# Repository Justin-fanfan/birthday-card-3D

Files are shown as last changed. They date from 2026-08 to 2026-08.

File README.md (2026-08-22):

# birthday-card-3D

用于生日礼物的 **掼蛋牌架 + A/B 双滑槽计级器 + 可插拔红桃 A 二维码展示牌**。

这一版把原来的独立横梁和旋钮结构改成了更接近 AI 参考模型的一体式外形：三层牌槽下方完全填充并彼此连接，装配预览中只保留中间的红桃 A，不再摆放其它演示牌。

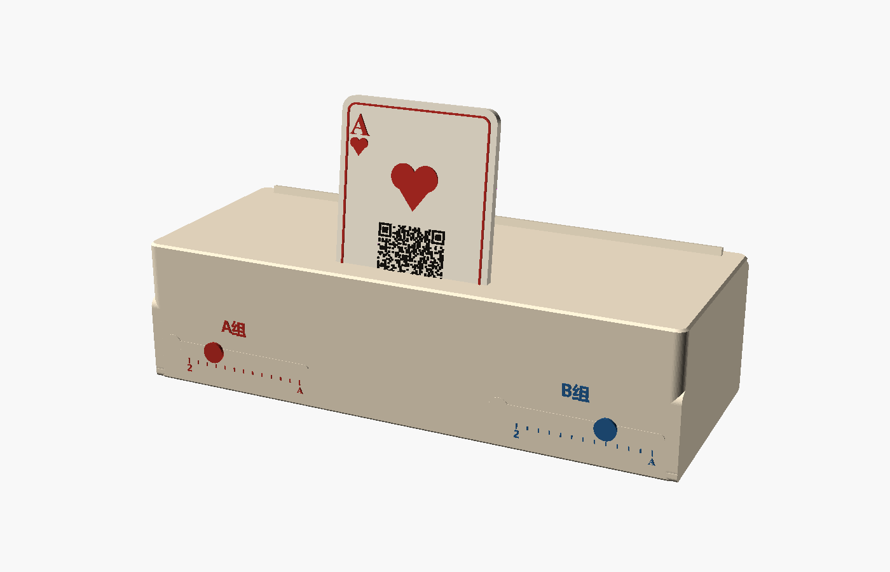
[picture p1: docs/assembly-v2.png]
assembly preview


## 结构概览

- 主体尺寸：`210 × 84 × 53 mm`
- 三排真实扑克牌槽：`2.4 mm` 宽、`10 mm` 深、后仰 `12°`
- 连续阶梯主体：相邻层重叠连接，不留会掉牌的大缝
- 红桃 A：`60 × 90 × 3.2 mm`，带红色浮雕和真实二维码浮雕
- 左右各一条横向计级滑轨，带 13 个刻度和 `2 / A` 端点标记
- 两个相同的独立滑块，平放打印，无需支撑
- 滑轨采用“窄开口 + 隐藏宽腔 + 端部装入口”，滑块装入后不会从普通位置直接掉出

侧面连续轮廓：

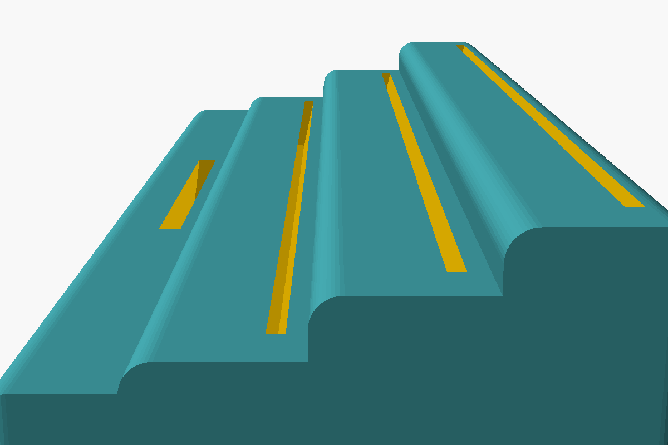
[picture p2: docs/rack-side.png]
continuous side profile


## 1. 生成二维码几何

仓库里的 `qr.svg` 带白色背景。OpenSCAD 直接导入会把它识别成实心方块，因此使用脚本提取黑色 QR 模块：

```powershell
python .\tools\prepare_qr.py
```

脚本会生成 `qr_data.scad`。当前二维码为 `43 × 43`，在 30 mm 宽度下单模块约 `0.698 mm`。

> 几何可打印不等于实体一定容易扫描。最终交付前仍需用实际耗材打印红桃 A，并用手机测试扫码。

## 2. OpenSCAD 输出

打开 `rack.scad`，通过 `part` 选择预览或零件：

| `part` | 内容 |
|---|---|
| `assembly` | 完整彩色装配预览，仅展示红桃 A |
| `rack` | 一体式牌架主体 |
| `heartA` | 红桃 A 完整单色 STL |
| `heartA_base` | 红桃 A 底板 |
| `heartA_red` | 红色浮雕层 |
| `heartA_black` | 黑色二维码/文字浮雕层 |
| `sliderA` / `sliderB` | 两个相同的计级滑块 |
| `slot_test` | 普通牌槽和红桃 A 插槽公差测试 |
| `slider_test` | 短滑轨 + 一个滑块的装配公差测试 |

也可以运行：

```powershell
.\export.ps1
```

脚本会先生成二维码数据，再把可打印 STL 导出到 `out/`。

## 3. 今晚打印顺序

不要先打印 210 mm 主体。推荐顺序：

1. `slot_test`：用真实扑克牌和红桃 A 厚度检查槽宽
2. `slider_test`：确认滑块能从圆形装入口压入，并能在窄槽中顺畅移动
3. `heartA`：平放、浮雕朝上；打印后检查二维码
4. `rack`：底面直接贴热床
5. `sliderA`、`sliderB`：背部圆盘朝下平放

滑块装配方法：

1. 将滑块背部 `6.0 mm` 圆形挡边对准滑轨最左侧的 `7.4 mm` 圆形装入口
2. 轻压进入隐藏腔体
3. 沿横槽推向第一个刻度；离开装入口后，挡边会被窄开口留在轨道内

如果 `slider_test` 偏紧，优先把 `score_cavity_h` 和 `score_open_h` 各增加 `0.2 mm`，不要直接重打主体。

## 4. 推荐 FDM 参数

0.4 mm 喷嘴 / PLA：

- 层高：`0.16~0.20 mm`
- 壁数：`3~4`
- 顶/底层：`5~6`
- 填充：`15~20%`
- 外墙：`40~50 mm/s`
- 主体支撑：通常不需要；隐藏滑轨顶部只有约 4 mm 短桥接
- 主体摆放：底面朝下
- 红桃 A：浮雕朝上
- 滑块：背部圆盘朝下

主体宽度保持在 210 mm，是为了给常见的 220 mm 热床留出边界余量。

## 5. 多色与单色方案

推荐配色：

- 牌架主体：米白 / 象牙白
- 红桃 A 的 `A / ♥ / 边框`：红色
- 二维码和文字：黑色
- A 组滑块：红色
- B 组滑块：蓝色

没有 AMS 时，可以单色打印，再用丙烯笔或油漆笔给浮雕顶面点色。

## 6. 字体

默认针对 Windows：

```scad
font_main  = "Microsoft YaHei:style=Bold";
font_latin = "Times New Roman:style=Bold";
```

如果 OpenSCAD 出现缺字，可在 `Help -> Font List` 中换成系统已有字体。

## 本地验证

开发时使用 OpenSCAD 2021.01：

- 完成 `assembly` 彩色预览和 `rack` 正面/侧面渲染
- 对 `rack / heartA / sliderA / sliderB / slot_test / slider_test` 执行 STL 导出
- 检查 STL 的连通性、边界边和非流形边

以上验证覆盖代码和网格结构，不替代真实打印机上的尺寸公差测试；正式大件前仍应先打两个测试件。

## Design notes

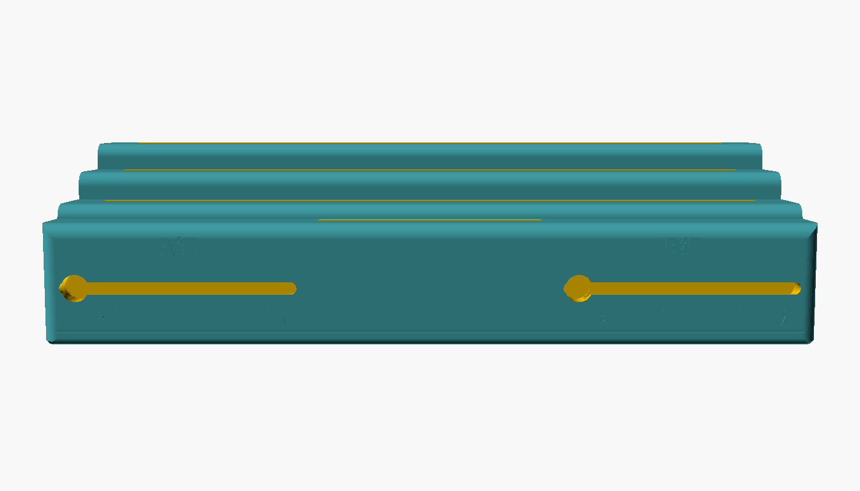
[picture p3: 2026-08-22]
docs/rack-front.png

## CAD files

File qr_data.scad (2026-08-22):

// AUTO-GENERATED by tools/prepare_qr.py — do not edit by hand.
qr_ready = true;
qr_grid = 43;
qr_modules = [
    [3, 3],
    [4, 3],
    [5, 3],
    [6, 3],
    [7, 3],
    [8, 3],
    [9, 3],
    [14, 3],
    [16, 3],
    [17, 3],
    [20, 3],
    [23, 3],
    [25, 3],
    [31, 3],
    [33, 3],
    [34, 3],
    [35, 3],
    [36, 3],
    [37, 3],
    [38, 3],
    [39, 3],
    [3, 4],
    [9, 4],
    [11, 4],
    [15, 4],
    [16, 4],
    [20, 4],
    [22, 4],
    [23, 4],
    [24, 4],
    [25, 4],
    [29, 4],
    [30, 4],
    [31, 4],
    [33, 4],
    [39, 4],
    [3, 5],
    [5, 5],
    [6, 5],
    [7, 5],
    [9, 5],
    [14, 5],
    [16, 5],
    [17, 5],
    [18, 5],
    [19, 5],
    [23, 5],
    [25, 5],
    [26, 5],
    [29, 5],
    [31, 5],
    [33, 5],
    [35, 5],
    [36, 5],
    [37, 5],
    [39, 5],
    [3, 6],
    [5, 6],
    [6, 6],
    [7, 6],
    [9, 6],
    [13, 6],
    [14, 6],
    [16, 6],
    [17, 6],
    [19, 6],
    [21, 6],
    [22, 6],
    [25, 6],
    [27, 6],
    [29, 6],
    [30, 6],
    [33, 6],
    [35, 6],
    [36, 6],
    [37, 6],
    [39, 6],
    [3, 7],
    [5, 7],
    [6, 7],
    [7, 7],
    [9, 7],
    [11, 7],
    [12, 7],
    [13, 7],
    [14, 7],
    [17, 7],
    [19, 7],
    [20, 7],
    [22, 7],
    [25, 7],
    [26, 7],
    [28, 7],
    [29, 7],
    [30, 7],
    [33, 7],
    [35, 7],
    [36, 7],
    [37, 7],
    [39, 7],
    [3, 8],
    [9, 8],
    [13, 8],
    [14, 8],
    [15, 8],
    [17, 8],
    [21, 8],
    [22, 8],
    [24, 8],
    [26, 8],
    [27, 8],
    [29, 8],
    [30, 8],
    [31, 8],
    [33, 8],
    [39, 8],
    [3, 9],
    [4, 9],
    [5, 9],
    [6, 9],
    [7, 9],
    [8, 9],
    [9, 9],
    [11, 9],
    [13, 9],
    [15, 9],
    [17, 9],
    [19, 9],
    [21, 9],
    [23, 9],
    [25, 9],
    [27, 9],
    [29, 9],
    [31, 9],
    [33, 9],
    [34, 9],
    [35, 9],
    [36, 9],
    [37, 9],
    [38, 9],
    [39, 9],
    [12, 10],
    [14, 10],
    [15, 10],
    [16, 10],
    [18, 10],
    [19, 10],
    [24, 10],
    [25, 10],
    [26, 10],
    [30, 10],
    [31, 10],
    [3, 11],
    [5, 11],
    [7, 11],
    [9, 11],
    [13, 11],
    [17, 11],
    [23, 11],
    [25, 11],
    [26, 11],
    [30, 11],
    [31, 11],
    [35, 11],
    [38, 11],
    [3, 12],
    [5, 12],
    [6, 12],
    [7, 12],
    [8, 12],
    [11, 12],
    [14, 12],
    [15, 12],
    [17, 12],
    [18, 12],
    [20, 12],
    [22, 12],
    [23, 12],
    [25, 12],
    [26, 12],
    [28, 12],
    [30, 12],
    [31, 12],
    [32, 12],
    [35, 12],
    [39, 12],
    [7, 13],
    [9, 13],
    [10, 13],
    [11, 13],
    [12, 13],
    [13, 13],
    [20, 13],
    [21, 13],
    [22, 13],
    [23, 13],
    [25, 13],
    [29, 13],
    [30, 13],
    [31, 13],
    [37, 13],
    [38, 13],
    [39, 13],
    [3, 14],
    [7, 14],
    [12, 14],
    [14, 14],
    [15, 14],
    [16, 14],
    [18, 14],
    [20, 14],
    [23, 14],
    [24, 14],
    [26, 14],
    [28, 14],
    [29, 14],
    [31, 14],
    [32, 14],
    [33, 14],
    [35, 14],
    [36, 14],
    [38, 14],
    [4, 15],
    [5, 15],
    [6, 15],
    [7, 15],
    [8, 15],
    [9, 15],
    [11, 15],
    [15, 15],
    [16, 15],
    [19, 15],
    [20, 15],
    [22, 15],
    [23, 15],
    [24, 15],
    [27, 15],
    [28, 15],
    [30, 15],
    [31, 15],
    [32, 15],
    [33, 15],
    [38, 15],
    [39, 15],
    [4, 16],
    [5, 16],
    [6, 16],
    [7, 16],
    [15, 16],
    [16, 16],
    [17, 16],
    [19, 16],
    [20, 16],
    [21, 16],
    [23, 16],
    [25, 16],
    [27, 16],
    [28, 16],
    [33, 16],
    [38, 16],
    [39, 16],
    [7, 17],
    [9, 17],
    [11, 17],
    [13, 17],
    [14, 17],
    [21, 17],
    [24, 17],
    [29, 17],
    [31, 17],
    [33, 17],
    [34, 17],
    [37, 17],
    [38, 17],
    [39, 17],
    [3, 18],
    [4, 18],
    [5, 18],
    [8, 18],
    [13, 18],
    [14, 18],
    [15, 18],
    [17, 18],
    [18, 18],
    [19, 18],
    [20, 18],
    [21, 18],
    [23, 18],
    [27, 18],
    [28, 18],
    [29, 18],
    [31, 18],
    [35, 18],
    [38, 18],
    [39, 18],
    [4, 19],
    [6, 19],
    [7, 19],
    [9, 19],
    [13, 19],
    [15, 19],
    [17, 19],
    [18, 19],
    [19, 19],
    [21, 19],
    [22, 19],
    [27, 19],
    [29, 19],
    [30, 19],
    [33, 19],
    [34, 19],
    [35, 19],
    [36, 19],
    [39, 19],
    [6, 20],
    [10, 20],
    [16, 20],
    [17, 20],
    [18, 20],
    [19, 20],
    [20, 20],
    [21, 20],
    [22, 20],
    [24, 20],
    [26, 20],
    [27, 20],
    [29, 20],
    [30, 20],
    [34, 20],
    [37, 20],
    [39, 20],
    [3, 21],
    [8, 21],
    [9, 21],
    [11, 21],
    [13, 21],
    [14, 21],
    [15, 21],
    [18, 21],
    [19, 21],
    [26, 21],
    [27, 21],
    [28, 21],
    [32, 21],
    [33, 21],
    [34, 21],
    [35, 21],
    [36, 21],
    [38, 21],
    [39, 21],
    [6, 22],
    [7, 22],
    [10, 22],
    [14, 22],
    [15, 22],
    [19, 22],
    [20, 22],
    [22, 22],
    [24, 22],
    [25, 22],
    [27, 22],
    [28, 22],
    [30, 22],
    [34, 22],
    [36, 22],
    [38, 22],
    [3, 23],
    [7, 23],
    [9, 23],
    [15, 23],
    [17, 23],
    [18, 23],
    [19, 23],
    [20, 23],
    [23, 23],
    [24, 23],
    [26, 23],
    [27, 23],
    [28, 23],
    [31, 23],
    [32, 23],
    [33, 23],
    [37, 23],
    [3, 24],
    [5, 24],
    [6, 24],
    [7, 24],
    [11, 24],
    [12, 24],
    [15, 24],
    [16, 24],
    [24, 24],
    [27, 24],
    [31, 24],
    [33, 24],
    [34, 24],
    [36, 24],
    [39, 24],
    [3, 25],
    [4, 25],
    [5, 25],
    [6, 25],
    [7, 25],
    [8, 25],
    [9, 25],
    [12, 25],
    [13, 25],
    [16, 25],
    [20, 25],
    [25, 25],
    [27, 25],
    [28, 25],
    [32, 25],
    [34, 25],
    [37, 25],
    [38, 25],
    [39, 25],
    [3, 26],
    [7, 26],
    [8, 26],
    [11, 26],
    [16, 26],
    [17, 26],
    [18, 26],
    [23, 26],
    [24, 26],
    [25, 26],
    [27, 26],
    [30, 26],
    [32, 26],
    [33, 26],
    [35, 26],
    [7, 27],
    [9, 27],
    [10, 27],
    [11, 27],
    [12, 27],
    [15, 27],
    [16, 27],
    [18, 27],
    [22, 27],
    [23, 27],
    [25, 27],
    [26, 27],
    [30, 27],
    [31, 27],
    [32, 27],
    [35, 27],
    [36, 27],
    [39, 27],
    [8, 28],
    [14, 28],
    [18, 28],
    [22, 28],
    [23, 28],
    [24, 28],
    [25, 28],
    [26, 28],
    [28, 28],
    [30, 28],
    [31, 28],
    [32, 28],
    [35, 28],
    [37, 28],
    [38, 28],
    [39, 28],
    [3, 29],
    [5, 29],
    [6, 29],
    [7, 29],
    [9, 29],
    [10, 29],
    [16, 29],
    [21, 29],
    [22, 29],
    [23, 29],
    [24, 29],
    [25, 29],
    [28, 29],
    [30, 29],
    [31, 29],
    [33, 29],
    [38, 29],
    [39, 29],
    [4, 30],
    [5, 30],
    [8, 30],
    [14, 30],
    [15, 30],
    [17, 30],
    [18, 30],
    [20, 30],
    [23, 30],
    [24, 30],
    [26, 30],
    [28, 30],
    [31, 30],
    [33, 30],
    [35, 30],
    [37, 30],
    [38, 30],
    [39, 30],
    [3, 31],
    [7, 31],
    [8, 31],
    [9, 31],
    [13, 31],
    [15, 31],
    [17, 31],
    [20, 31],
    [22, 31],
    [23, 31],
    [24, 31],
    [25, 31],
    [27, 31],
    [28, 31],
    [30, 31],
    [31, 31],
    [32, 31],
    [33, 31],
    [34, 31],
    [35, 31],
    [37, 31],
    [38, 31],
    [11, 32],
    [14, 32],
    [15, 32],
    [19, 32],
    [20, 32],
    [23, 32],
    [28, 32],
    [30, 32],
    [31, 32],
    [35, 32],
    [36, 32],
    [38, 32],
    [39, 32],
    [3, 33],
    [4, 33],
    [5, 33],
    [6, 33],
    [7, 33],
    [8, 33],
    [9, 33],
    [12, 33],
    [14, 33],
    [15, 33],
    [16, 33],
    [21, 33],
    [24, 33],
    [27, 33],
    [29, 33],
    [30, 33],
    [31, 33],
    [33, 33],
    [35, 33],
    [36, 33],
    [38, 33],
    [39, 33],
    [3, 34],
    [9, 34],
    [16, 34],
    [18, 34],
    [20, 34],
    [21, 34],
    [22, 34],
    [27, 34],
    [28, 34],
    [29, 34],
    [31, 34],
    [35, 34],
    [36, 34],
    [39, 34],
    [3, 35],
    [5, 35],
    [6, 35],
    [7, 35],
    [9, 35],
    [11, 35],
    [12, 35],
    [14, 35],
    [15, 35],
    [16, 35],
    [17, 35],
    [19, 35],
    [21, 35],
    [22, 35],
    [26, 35],
    [27, 35],
    [29, 35],
    [31, 35],
    [32, 35],
    [33, 35],
    [34, 35],
    [35, 35],
    [36, 35],
    [39, 35],
    [3, 36],
    [5, 36],
    [6, 36],
    [7, 36],
    [9, 36],
    [15, 36],
    [18, 36],
    [19, 36],
    [20, 36],
    [21, 36],
    [22, 36],
    [26, 36],
    [27, 36],
    [28, 36],
    [29, 36],
    [30, 36],
    [34, 36],
    [35, 36],
    [36, 36],
    [38, 36],
    [39, 36],
    [3, 37],
    [5, 37],
    [6, 37],
    [7, 37],
    [9, 37],
    [11, 37],
    [12, 37],
    [14, 37],
    [16, 37],
    [17, 37],
    [18, 37],
    [19, 37],
    [24, 37],
    [26, 37],
    [27, 37],
    [29, 37],
    [30, 37],
    [31, 37],
    [32, 37],
    [35, 37],
    [36, 37],
    [37, 37],
    [39, 37],
    [3, 38],
    [9, 38],
    [12, 38],
    [13, 38],
    [14, 38],
    [15, 38],
    [16, 38],
    [17, 38],
    [19, 38],
    [20, 38],
    [22, 38],
    [24, 38],
    [27, 38],
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

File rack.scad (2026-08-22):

/*
 * Birthday GuanDan rack - continuous stepped edition
 * OpenSCAD 2021.01 compatible.
 *
 * part = "assembly" | "rack" | "heartA" | "heartA_base" |
 *        "heartA_red" | "heartA_black" | "sliderA" | "sliderB" |
 *        "slot_test" | "slider_test"
 */

include <qr_data.scad>

$fn = 48;

part = "assembly";
show_score_labels = true;
show_qr = true;

// ---------- continuous rack ----------
rack_w = 210;
rack_d = 84;
base_t = 5;
corner_r = 4;
edge_bevel = 0.9;

front_d = 25;
front_h = 33;

// Overlapping rounded masses form one continuous, gap-free stepped body.
tier1_y = 17; tier1_d = 31; tier1_h = 37; row1_y = 34;
tier2_y = 39; tier2_d = 31; tier2_h = 45; row2_y = 56;
tier3_y = 61; tier3_d = 23; tier3_h = 53; row3_y = 77;

card_slot_len = 192;
card_slot_w = 2.4;
card_slot_depth = 10;
card_lean = 12;

display_slot_len = 62;
display_slot_w = 3.8;
display_slot_depth = 10;
display_lean = 8;
display_y = 12;

// ---------- simple captive score sliders ----------
score_track_len = 64;
score_track_z = 15.5;
score_left_x = 5;
score_right_x = rack_w - score_left_x - score_track_len;
score_load_offset = 4.2;
score_first_offset = 11;
score_last_offset = 60;
score_open_h = 3.4;
score_cavity_h = 6.6;
score_load_d = 7.4;
score_open_depth = 2.8;
score_cavity_y = 1.8;
score_cavity_depth = 4.2;
score_label_size = 4.5;
score_text_size = 2.7;

slider_flange_d = 6.0;
slider_flange_t = 1.5;
slider_neck_d = 3.0;
slider_neck_h = 2.8;
slider_knob_d = 8.2;
slider_knob_h = 2.3;
slider_assembly_y = score_cavity_y + score_cavity_depth - 1.1;

levels = ["2","3","4","5","6","7","8","9","10","J","Q","K","A"];

// ---------- heart A ----------
card_w = 60;
card_h = 90;
card_t = 3.2;
card_r = 5;
relief_h = 0.65;
border_w = 0.65;
qr_size = 30;
font_main = "Microsoft YaHei:style=Bold";
font_latin = "Times New Roman:style=Bold";

// ------------------------------------------------------------
// Shared 2D/3D helpers
// ------------------------------------------------------------
module rounded_rect_2d(w,d,r) {
    hull() {
        translate([r,r]) circle(r=r);
        translate([w-r,r]) circle(r=r);
        translate([r,d-r]) circle(r=r);
        translate([w-r,d-r]) circle(r=r);
    }
}

module soft_prism(w,d,h,r=3,b=0.8) {
    hull() {
        translate([b,b,0]) linear_extrude(height=0.05)
            rounded_rect_2d(w-2*b,d-2*b,max(0.5,r-b));
        translate([0,0,b]) linear_extrude(height=0.05)
            rounded_rect_2d(w,d,r);
        translate([0,0,h-b]) linear_extrude(height=0.05)
            rounded_rect_2d(w,d,r);
        translate([b,b,h-0.05]) linear_extrude(height=0.05)
            rounded_rect_2d(w-2*b,d-2*b,max(0.5,r-b));
    }
}

// Extrude a YZ side profile along world X.
module extrude_side_profile(width) {
    multmatrix([
        [0,0,1,0],
        [1,0,0,0],
        [0,1,0,0],
        [0,0,0,1]
    ]) linear_extrude(height=width) children();
}

// ------------------------------------------------------------
// Gap-free, continuous rack body
// ------------------------------------------------------------
module rack_side_profile_2d() {
    union() {
        // A full base closes the shallow rounding at every step.
        rounded_rect_2d(rack_d,base_t,1.8);
        rounded_rect_2d(front_d,front_h,4.2);
        translate([tier1_y,0]) rounded_rect_2d(tier1_d,tier1_h,4.2);
        translate([tier2_y,0]) rounded_rect_2d(tier2_d,tier2_h,4.2);
        translate([tier3_y,0]) rounded_rect_2d(tier3_d,tier3_h,4.2);
    }
}

module rack_solid() {
    // The envelope rounds the left/right footprint while the YZ profile
    // provides the flowing, fully filled stepped silhouette.
    intersection() {
        extrude_side_profile(rack_w) rack_side_profile_2d();
        soft_prism(rack_w,rack_d,tier3_h+2,corner_r,edge_bevel);
    }
}

module slot_cutter(y,z_top,len,width,depth,lean) {
    translate([rack_w/2,y,z_top-depth/2+1])
        rotate([-lean,0,0])
            cube([len,width,depth+8],center=true);
}

module card_slot_cutters() {
    slot_cutter(row1_y,tier1_h,card_slot_len,card_slot_w,card_slot_depth,card_lean);
    slot_cutter(row2_y,tier2_h,card_slot_len,card_slot_w,card_slot_depth,card_lean);
    slot_cutter(row3_y,tier3_h,card_slot_len,card_slot_w,card_slot_depth,card_lean);
}

module display_slot_cutter() {
    slot_cutter(display_y,front_h,display_slot_len,display_slot_w,display_slot_depth,display_lean);
}

module y_cylinder(x,y,z,d,depth) {
    translate([x,y+depth,z])
        rotate([90,0,0]) cylinder(h=depth,d=d);
}

module horizontal_pill(x0,len,y,z,d,depth) {
    hull() {
        y_cylinder(x0+d/2,y,z,d,depth);
        y_cylinder(x0+len-d/2,y,z,d,depth);
    }
}

module score_track_cutter(x0,len=score_track_len,z=score_track_z) {
    // Narrow visible opening plus a wider hidden cavity retains the slider.
    horizontal_pill(x0,len,-0.2,z,score_open_h,score_open_depth+0.2);
    horizontal_pill(x0,len,score_cavity_y,z,score_cavity_h,score_cavity_depth);

    // The rear flange enters through this port, then moves into the track.
    y_cylinder(x0+score_load_offset,-0.2,z,score_load_d,
        score_cavity_y+score_cavity_depth+0.4);
}

module score_track_cutters() {
    score_track_cutter(score_left_x);
    score_track_cutter(score_right_x);
}

module rack_base_geometry() {
    difference() {
        rack_solid();
        card_slot_cutters();
        display_slot_cutter();
        score_track_cutters();
    }
}

// ------------------------------------------------------------
// Front-face score graphics
// ------------------------------------------------------------
module face_text(str,x,z,size=4.5,depth=0.55,font=font_main) {
    translate([x,0.25,z])
        rotate([90,0,0])
            linear_extrude(height=depth)
                text(str,size=size,font=font,halign="center",valign="center");
}

module face_tick(x,z,h=1.7,w=0.45,depth=0.5) {
    translate([x,0.25,z])
        rotate([90,0,0])
            linear_extrude(height=depth)
                square([w,h],center=true);
}

function score_x(x0,i) =
    x0 + score_first_offset + i*(score_last_offset-score_first_offset)/12;

module score_scale(x0,label) {
    face_text(label,x0+score_track_len/2,26.7,score_label_size);
    for (i=[0:12]) face_tick(score_x(x0,i),9.6,(i==0 || i==12) ? 2.2 : 1.5);
    face_text("2",score_x(x0,0),6.6,score_text_size);
    face_text("A",score_x(x0,12),6.6,score_text_size,font=font_latin);
}

module score_face_details() {
    if (show_score_labels) {
        score_scale(score_left_x,"A组");
        score_scale(score_right_x,"B组");
    }
}

module rack() {
    union() {
        rack_base_geometry();
        score_face_details();
    }
}

// ------------------------------------------------------------
// Captive slider: print flat on its rear flange, no support.
// ------------------------------------------------------------
module slider() {
    union() {
        cylinder(h=slider_flange_t,d=slider_flange_d);
        translate([0,0,slider_flange_t-0.1])
            cylinder(h=slider_neck_h+0.2,d=slider_neck_d);
        hull() {
            translate([0,0,slider_flange_t+slider_neck_h-0.05])
                cylinder(h=0.1,d=slider_knob_d-0.8);
            translate([0,0,slider_flange_t+slider_neck_h+slider_knob_h-0.1])
                cylinder(h=0.1,d=slider_knob_d);
        }
    }
}

module slider_standing_colored(x,z,color_value) {
    translate([x,slider_assembly_y,z]) rotate([90,0,0])
        color(color_value) slider();
}

// ------------------------------------------------------------
// Heart A card
// ------------------------------------------------------------
module heart_2d(s=1) {
    scale([s,s]) union() {
        translate([-3.2,1.8]) circle(r=3.5);
        translate([ 3.2,1.8]) circle(r=3.5);
        polygon(points=[[-6.5,1.5],[6.5,1.5],[0,-7.0]]);
    }
}

module card_base() {
    linear_extrude(height=card_t)
        rounded_rect_2d(card_w,card_h,card_r);
}

module card_red_relief() {
    z = card_t - 0.05;
    translate([0,0,z]) linear_extrude(height=relief_h)
        difference() {
            translate([2.4,2.4]) rounded_rect_2d(card_w-4.8,card_h-4.8,3.2);
            translate([3.1,3.1]) rounded_rect_2d(card_w-6.2,card_h-6.2,2.6);
        }
    translate([7.5,80,z]) linear_extrude(height=relief_h)
        text("A",size=8,font=font_latin,halign="center",valign="center");
    translate([7.5,72.5,z]) linear_extrude(height=relief_h) heart_2d(0.52);
    translate([card_w/2,61,z]) linear_extrude(height=relief_h) heart_2d(1.35);
    translate([52.5,10,z]) rotate([0,0,180]) linear_extrude(height=relief_h)
        text("A",size=7,font=font_latin,halign="center",valign="center");
    translate([52.5,17,z]) rotate([0,0,180]) linear_extrude(height=relief_h)
        heart_2d(0.42);
}

module qr_2d(target_size=30) {
    cell = target_size / qr_grid;
    union() {
        for (p = qr_modules)
            translate([p[0]*cell, (qr_grid-1-p[1])*cell])
                square([cell*1.002,cell*1.002]);
    }
}
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

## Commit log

2026-08-22 feat: refine Guandan rack and integrated gift card
    [rack.scad]
2026-08-22 chore: add safe QR data placeholder
    [qr_data.scad]
2026-08-22 docs: add print and assembly workflow
2026-08-22 build: add Windows STL export helper
2026-08-22 feat: redesign rack with continuous tiers and sliders
    [qr_data.scad, rack.scad]
